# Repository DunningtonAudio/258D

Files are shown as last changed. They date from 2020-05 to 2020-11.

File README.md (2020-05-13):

# 258D
A dual oscillator project

The 258D Dual Oscillator is designed to replicate the functionality of the Buchla 258C module using modern construction techniques and readily available parts. Like Mark Verbos’ 258V and Dustin Stroh’s 258J, the 258D uses the exponential converter and triangle core from the Electronotes VCO option 3, designed by Bernie Hutchins, with output waveshaping derived from Don Buchla’s original 258 Design.

Additionally, the 258D includes:

* A stable voltage reference to isolate the frequency controls from fluctuations and noise on the power supply rails.
* High frequency compensation for improved tracking.
* A scaled V/O CV input in place of the original scaling potentiometer.
* The option to select either saw or square waveshapes for each oscillator by setting a jumper on the rear of the module.
* A buffered copy of the triangle core replacing the rightmost output of each oscillator.
 
There are several build options to adjust the function of the module to a particular users requirements.

The repository contains:

* KiCad project files
* Schematic and build/calibration notes as PDF files
* Bill of Materials in ODS format
* Interactive webpage for matching BOM items to PCB locations

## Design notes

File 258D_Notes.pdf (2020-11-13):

258D Dual Oscillator

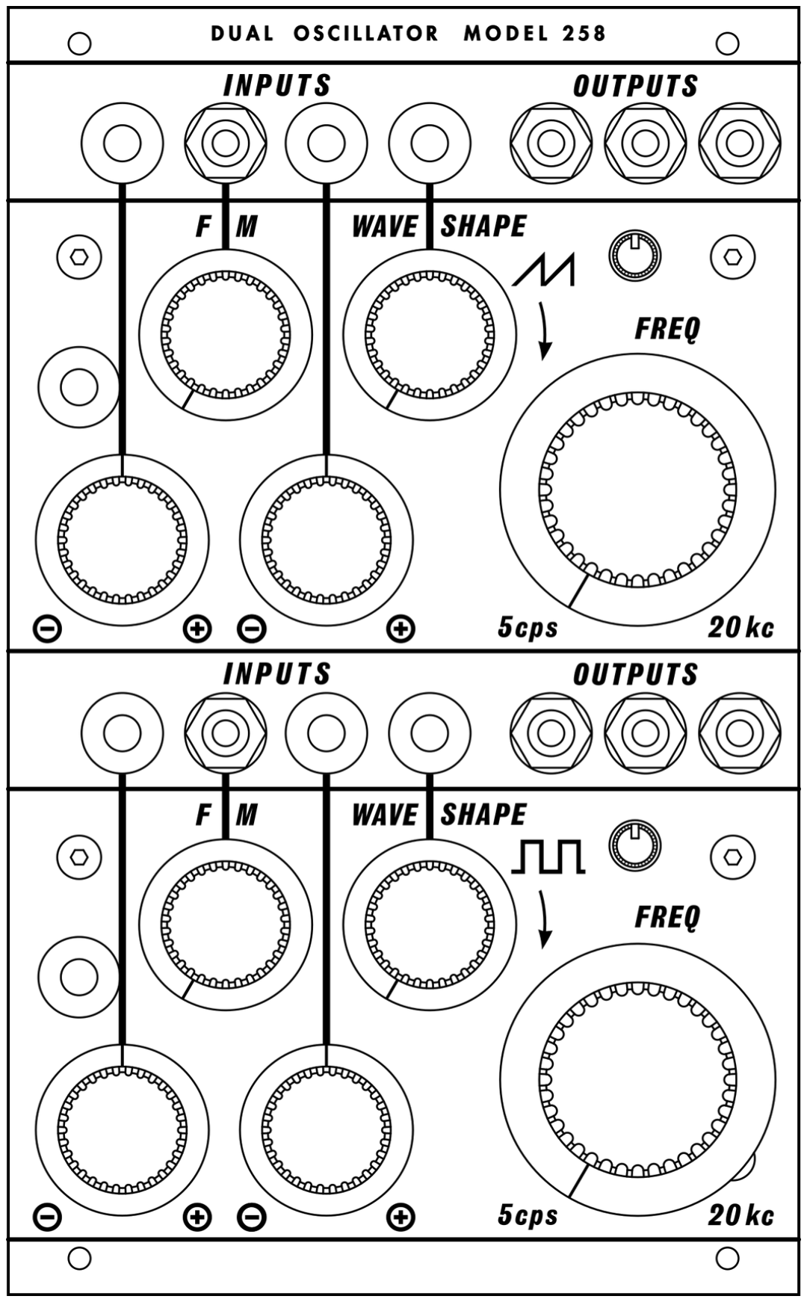
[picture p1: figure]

The 258D Dual Oscillator is designed to replicate the functionality of the Buchla 258C module using modern construction techniques and readily available parts. Like Mark Verbos’ 258V and Dustin Stroh’s 258J, the 258D uses the exponential converter and triangle core from the Electronotes VCO option 3, designed by Bernie Hutchins, with output waveshaping derived from Don Buchla’s original 258 Design.

Additionally, the 258D includes:

- A stable voltage reference to isolate the frequency controls from fluctuations and noise on the power supply rails
- High frequency compensation for improved tracking
- A scaled V/O CV input in place of the original scaling potentiometer
- The option to select either saw or square waveshapes for each oscillator by setting a jumper on the rear of the module
- A buffered copy of the triangle core replacing the rightmost output of each oscillator

Build Notes:

** The 258D is designed to be suitable for hand assembly, but it is not recommended as a “learn surface mount” starting point. You should at a minimum have a temperature controlled soldering iron with a reasonably fine point and good quality solder 0.5mm diameter or finer. Some form of magnification may be beneficial for placing/inspecting the SOT-363 packages. **

Note that Q105/205 should have their VGS(off) selected between 0.8V and 1.2V for best sine shape (ideal value is 1.13V), you should buy more than you need for the best chance of success.

It is recommended that the circuit board is populated in the following order:

- SOT-363 packages (note polarity – these are not symmetrical!)
- SOT-23 packages
- SOIC packages
- 0805 passives (Use the minimum temperature/time possible when soldering film capacitors C101/201)
- Trimmer potentiometers
- Electrolytic capacitors
- Through hole pin headers
- Power wiring harness

Connectors should have their wire links attached and be mounted to the front panel, along with standoffs. Front panel potentiometers can then be loosely fitted into the PCB and the panel and PCB brought together before gently tightening the potentiometer fixing nuts and soldering the potentiometers and connector to PCB wires into place.

Modifications:

There are a number of changes that can be made to alter the behaviour of the module to suit the needs of the end user:

- Resistors R103/203 set the range of the coarse frequency pot. A value of 150k matches the response approximately to the front panel scale of 5Hz to 20kHz. A value of 180k reduces the range to around 5Hz to 12kHz which improves the ease of tuning if using the oscillators for pitched material. Higher frequencies are still available using external CV.
- Resistors R105/205 set the range of the V/O scaling. A value of 120k gives good adjustment for 1.2 V/O scaling. For 1 V/O scaling, reduce the value, or for 2 V/O scaling increase it.
- The waveshapes available from each oscillator can be selected between sine/saw and sine/square by changing the location of a jumper on the rear of the PCB. After changing this setting, SHAPE ZERO should be recalibrated.

Calibration procedure:

Equipment required:
- Power supply delivering +/- 15V, current limit at 50mA
- Oscilloscope
- DC Voltage source capable of 0-10V to 1mV accuracy
- Frequency counter and/or tuner

The following steps should be repeated for each oscillator:

1. Fit shape select jumpers for desired shape on both oscillators.
2. Set front panel controls as follows:
- VR103/104/203/24 CV inputs 1 & 2 – Centre
- VR105/205 FM input – Fully CCW
- VR106/206 Wave Shape – Fully CCW
- VR101/201 Coarse Frequency – Fully CCW
- VR102/202 Fine tune - Centre
3. Set trimpots as follows (direction as viewed from the rear of the module):
- TR103/203 V/O SCALE – Centre
- TR102/202 HF COMP – Fully CW
- TR105/205 SHAPE ZERO – Fully CW
- TR101/201 FREQ OFFSET – Centre
- TR104/204 SINE SHAPE – Centre
4. Apply power to the module and check for approx 35mA draw on each rail.
5. Connect the rightmost output of the oscillator to the oscilloscope and check for approx 4.5V pk-pk triangle wave. Repeat for leftmost output and check for approx 4.5V pk-pk sine wave.
6. Adjust coarse frequency control for approx. 1kHz output. Adjust SINE SHAPE trimpot for best sine shape. If a good sinewave cannot be obtained when the trimpot is fully CCW, decrease the value of R142/R242.
7. Adjust SHAPE ZERO trimpot CCW until a small spike becomes visible at the low peak of the sinewave output, then back off slightly. The front panel Wave Shape control should now give a good range of control from sine to saw/square. Reset the front panel control fully CCW. Check for roughly equivalent response when applying 10V from the DC voltage source to the wave shape CV input.
8. Connect the leftmost output of the oscillator to the frequency counter/tuner. Set the DC voltage source to 0V and connect its output to the scaled (grey) CV input of the oscillator. Using the front panel coarse/fine frequency controls, set the oscillator frequency to 16.35Hz/C0. Set the output of the DC voltage source to 6.0V and check the output frequency – if it is higher than 523.25Hz/C5, adjust the V/O SCALE trimpot slightly CCW, or slightly CW if the output is lower (reverse the direction if a 3314J single turn pot is used). Reset the DC voltage source to 0V, set the oscillator output to 16.35Hz/C0 using the front panel controls and repeat the above until the oscillator outputs exactly 16.35Hz/C0 with 0V applied and exactly 523.25Hz/C5 with 6.0V applied.
9. Set the DC voltage source to 7.2V and check the frequency of the output. If it is lower than 1.0465kHz/C6, adjust the HF COMP trimpot slightly CCW. Repeat step 8 and 9 until the best average response between the two is found. It is likely that C6 will be slightly sharp when the rest of the range is well tuned.
10. Set the DC voltage source to 0V. Set the front panel fine tune control to centre and the coarse frequency control fully CW and measure the frequency of the output. Adjust the FREQ OFFSET trimpot for approx 20kHz.

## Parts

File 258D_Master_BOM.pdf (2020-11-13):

258D_Master

Reference | Quantity | Value | Footprint | Manufacturer | MPN | Supplier | Order Code | Description | Notes
PCB Mount
C103 C203 | 2 | 100p | C0805 | Yageo | CC0805JRNPO9BN101 | Mouser | 603-CC0805JRNPO9BN101 | C0G, 50V, 5%
C104 C105 C204 C205 | 4 | 220p | C0805 | Yageo | CC0805JRNPO9BN221 | Mouser | 603-CC0805JRNPO9BN221 | C0G, 50V, 5%
C101 C201 | 2 | 2n2 | C0805 | Panasonic | ECH-U1C222GX5 | Mouser | 667-ECH-U1C222GX5 | PPS, 16V, 2%
C1-C4, C106-C113, C206-C213 | 20 | 100n | C0805 | Yageo | CC0805KRX7R9BB104 | Mouser | 603-CC0805KRX7R9BB104 | X7R,50V, 10%
C102 C114 C115 C202 C214 C215 | 6 | 22u | CE5x5.8 | Panasonic | EEE-FK1V220AR | Mouser | 667-EEE-FK1V220AR | 35V, 20%, 105deg
D101 D102 D201 D202 | 4 | BAW56 | SOT-23-3 | On Semiconductor | BAW56LT1G | Mouser | 863-BAW56LT1G | Common anode dual diode
L1 L2 L101 L102 L201 L202 | 6 | 10u | L0805 | Taiyo Yuden | LBC2012T100K | Mouser | 963-LBC2012T100K | 1.2R, 200mA, 10%
Q101 Q201 | 2 | DMMT3906W | SOT-363 | Diodes Inc | DMMT3906W-7-F | Mouser | 621-DMMT3906W-F | Dual matched PNP | Note polarity – these are not symmetrical!
Q102 Q202 | 2 | DMMT3904W | SOT-363 | Diodes Inc | DMMT3904W-7-F | Mouser | 621-DMMT3904W-F | Dual matched NPN | Note polarity – these are not symmetrical!
Q103 Q203 | 2 | MMBT3906 | SOT-23-3 | On Semiconductor | MMBT3906LT1G | Mouser | 863-MMBT3906LT1G | PNP
Q104 Q204 | 2 | MMBF5485 | SOT-23-3 | On Semiconductor | MMBF5485 | Mouser | 512-MMBF5485 | N-Channel JFET
Q105 Q205 | 2 | MMBFJ201 | SOT-23-3 | On Semiconductor | MMBFJ201 | Mouser | 512-MMBFJ201 | N-Channel JFET | Select for VGS(off) = 0.7V – 1.2V; ideal value is 1.13V
R117 R217 | 2 | 390R | R0805 | Yageo | RC0805FR-07390RL | Mouser | 603-RC0805FR-07390RL | 150V, 125mW, 1%, 100PPM
R146 R246 | 2 | 470R | R0805 | Yageo | RC0805FR-07470RL | Mouser | 603-RC0805FR-07470RL | 150V, 125mW, 1%, 100PPM
R140 R141 R148 R151 R152 R240 R241 R248 R251 R252 | 10 | 680R | R0805 | Yageo | RC0805FR-07680RL | Mouser | 603-RC0805FR-07680RL | 150V, 125mW, 1%, 100PPM
R114 R145 R214 R245 | 4 | 1k8 | R0805 | Yageo | RC0805FR-071K8L | Mouser | 603-RC0805FR-071K8L | 150V, 125mW, 1%, 100PPM
R116 R216 | 2 | 2k | R0805 | TE Connectivity | LT732K0JTG | Small Bear | 2530 | PTC 5% | Alt. Farnell p/n 1174317
R147 R247 | 2 | 2k2 | R0805 | Yageo | RC0805FR-072K2L | Mouser | 603-RC0805FR-072K2L | 150V, 125mW, 1%, 100PPM
R133 R233 | 2 | 2k49 | R0805 | Yageo | RC0805FR-072K49L | Mouser | 603-RC0805FR-072K49L | 150V, 125mW, 1%, 100PPM
R124 R149 R224 R249 | 4 | 3k3 | R0805 | Yageo | RC0805FR-073K3L | Mouser | 603-RC0805FR-073K3L | 150V, 125mW, 1%, 100PPM
R119 R219 | 2 | 4k99 | R0805 | Yageo | RC0805FR-074K99L | Mouser | 603-RC0805FR-074K99L | 150V, 125mW, 1%, 100PPM
R129 R142 R143 R229 R242 R243 | 6 | 6k8 | R0805 | Yageo | RC0805FR-076K8L | Mouser | 603-RC0805FR-076K8L | 150V, 125mW, 1%, 100PPM
R150 R250 | 2 | 9k1 | R0805 | Yageo | RC0805FR-079K1L | Mouser | 603-RC0805FR-079K1L | 150V, 125mW, 1%, 100PPM
| 10 | 10k | R0805 | Yageo | RC0805FR-0710KL | Mouser | 603-RC0805FR-0710KL | 150V, 125mW, 1%, 100PPM
R121 R125 R130 R221 R225 R230 | 6 | 15k | R0805 | Yageo | RC0805FR-0715KL | Mouser | 603-RC0805FR-0715KL | 150V, 125mW, 1%, 100PPM
R118 R144 R218 R244 | 4 | 33k | R0805 | Yageo | RC0805FR-0733KL | Mouser | 603-RC0805FR-0733KL | 150V, 125mW, 1%, 100PPM
R120 R126 R220 R226 | 4 | 68k | R0805 | Yageo | RC0805FR-0768KL | Mouser | 603-RC0805FR-0768KL | 150V, 125mW, 1%, 100PPM
R107 R111 R113 R207 R211 R213 | 6 | 100k | R0805 | Yageo | RC0805FR-07100KL | Mouser | 603-RC0805FR-07100KL | 150V, 125mW, 1%, 100PPM
R105 R205 | 2 | 120k | R0805 | Yageo | RC0805FR-07120KL | Mouser | 603-RC0805FR-07120KL | 150V, 125mW, 1%, 100PPM | SOT for correct V/O scaling
R103 R123 R128 R203 R223 R228 | 6 | 150k | R0805 | Yageo | RC0805FR-07150KL | Mouser | 603-RC0805FR-07150KL | 150V, 125mW, 1%, 100PPM
R101 R102 R201 R202 | 4 | 180k | R0805 | Yageo | RC0805FR-07180KL | Mouser | 603-RC0805FR-07180KL | 150V, 125mW, 1%, 100PPM
R134 R137 R138 R139 R234 R237 R238 R239 | 8 | 330k | R0805 | Yageo | RC0805FR-07330KL | Mouser | 603-RC0805FR-07330KL | 150V, 125mW, 1%, 100PPM
R112 R132 R212 R232 | 4 | 390k | R0805 | Yageo | RC0805FR-07390KL | Mouser | 603-RC0805FR-07390KL | 150V, 125mW, 1%, 100PPM
R135 R235 | 2 | 430k | R0805 | Yageo | RC0805FR-07430KL | Mouser | 603-RC0805FR-07430KL | 150V, 125mW, 1%, 100PPM
R127 R227 | 2 | 680k | R0805 | Yageo | RC0805FR-07680KL | Mouser | 603-RC0805FR-07680KL | 150V, 125mW, 1%, 100PPM
R131 R136 R231 R236 | 4 | 820k | R0805 | Yageo | RC0805FR-07820KL | Mouser | 603-RC0805FR-07820KL | 150V, 125mW, 1%, 100PPM
R108 R110 R208 R210 | 4 | 1M5 | R0805 | Yageo | RC0805FR-071M5L | Mouser | 603-RC0805FR-071M5L | 150V, 125mW, 1%, 100PPM
R104 R204 | 2 | 2M7 | R0805 | Yageo | RC0805FR-072M7L | Mouser | 603-RC0805FR-072M7L | 150V, 125mW, 1%, 100PPM
TR103 TR203 | 2 | 100R | 3314J | Bourns | 3224W-1-101E | Mouser | 652-3224W-1-101E | 500V,250mW, 20%, 100PPM
TR104 TR204 | 2 | 20k | 3314J | Bourns | 3314J-1-203E | Mouser | 652-3314J-1-203E | 500V,250mW, 20%, 100PPM
TR101 TR102 TR201 TR202 | 4 | 100k | 3314J | Bourns | 3314J-1-104E | Mouser | 652-3314J-1-104E | 500V,250mW, 20%, 100PPM
TR105 TR205 | 2 | 1M | 3314J | Bourns | 3314J-1-105E | Mouser | 652-3314J-1-105E | 500V,250mW, 20%, 100PPM
U1 | 1 | ADR01 | SOIC08 | Analog Devices | ADR01ARZ | Mouser | 584-ADR01ARZ | 10V reference, 0.1%, 3PPM
U101 U201 | 2 | TL074 | SOIC14 | Texas Instruments | TL074IDR | Mouser | 595-TL074IDR | Quad operational amplifier, JFET input
U102 U202 | 2 | LM13700 | SOIC16 | Texas Instruments | LM13700MX/NOPB | Mouser | 926-LM13700MX/NOPB | Dual transconductance amplifier
U103 U203 | 2 | TL072 | SOIC08 | Texas Instruments | TL072IDR | Mouser | 595-TL072IDR | Dual operational amplifier, JFET input
U2 U104 U204 | 3 | TL071 | SOIC08 | Texas Instruments | TL071IDR | Mouser | 595-TL071IDR | Operational amplifier, JFET input
VR102 VR202 | 2 | 100k Lin | RD901F-40-00D | Song Huei | R0904N-B100K-L-25KQ | Small Bear | 1012A4-B100K | 9mm RA PCB mount potentiometer
VR101 VR103 VR104 VR106 VR201 VR203 VR204 VR206 | 8 | 100k Lin | RV16AF-41-(L)R1-XXX | Alpha | RV16AF-41-15R1-104B | Small Bear | 1011 B100K | 16mm RA PCB mount potentiometer | Snap off locating lug
VR105 VR205 | 2 | 100k Log | RV16AF-41-(L)R1-XXX | Alpha | RV16AF-41-15R1-104A | Small Bear | 1011 A100K | 16mm RA PCB mount potentiometer | Snap off locating lug
| 10 | | | Alpha | M7x0.75 | Small Bear | 1018 | Toothed washer for 16mm potentiometer | Fit between potentiometer body and panel
| 10 | | | Alpha | | Small Bear | 1011AM | Dust cover for 16mm potentiometer | Fit on all 16mm potentiometers
J106-J108, J206-J208 | 2 | Shape Sel | | Samtec | TSW-103-07-F-T | Mouser | 200-TSW10307GT | 3R3P header 2.54mm | Alt. Farnell p/n 2050709

R1 R2 R106 R109 R115 R122 R206 R209 R215 R222

258D_Master

Reference | Quantity | Value | Footprint | Manufacturer | MPN | Supplier | Order Code | Description | Notes
Panel Mount
J101 J102 J105 J201 J202 J205 | 6 | CV inputs | Johnson | 108-0903-001 | Mouser | 530-108-0903-1 | Black banana jack
J103 J203 | 2 | V/O input | Johnson | 108-0913-001 | Mouser | 530-108-0913-1 | Grey banana jack
J104 J109 J110 J111 J204 J209 J210 J211 | 8 | Audio IO | Switchcraft | 41 | Mouser | 502-41 | Tinijax
24awg wire black 25mm length | 14 | | Alpha Wire | 892419 BK005 | Mouser | 602-892419-100-02 | Wiring to CV inputs + audio shields | Strip 4mm each end. Order code is for 30.5m reel.
24awg wire grey 25mm length | 2 | | Alpha Wire | 892419 SL005 | Mouser | 602-892419-100-09 | Wiring to V/O inputs | Strip 4mm each end. Order code is for 30.5m reel.
24awg wire white 25mm length | 8 | | Alpha Wire | 892419 WH005 | Mouser | 602-892419-100-01 | Wiring to Audio IO | Strip 4mm each end. Order code is for 30.5m reel.
Hardware & Misc
PCB | 1 | | Dunnington Audio | | thebeast.co.uk | http://thebeast.co.uk/?product=Printed circuit board
Front panel | 1 | | The Beast | | thebeast.co.uk | http://thebeast.co.uk/?product | Front panel | If using alternate panels, drill out the scale trim pot holes to 8.5mm
M3x14mm F-F Standoff | 5 | | Harwin | R30-1001402 | Mouser | 855-R30-1001402
M3x6mm Pozi CSK | 5 | | RS Pro | | RS | 528-946 | | Panel to standoff fixing
M3x6mm Pozi Pan SEMS | 5 | | RS Pro | | RS | 279-149 | | PCB to standoff fixing
M3 Toothed Washer | 5 | | RS Pro | | RS | 526-574 | | Fit between standoffs and panel
Small Knob | 8 | | Davies Molding | 1610AA | Mouser | 5164-1610AA | | Fit on VR103-VR106 & VR203-VR206
Large knob | 2 | | Davies Molding | 1600BM | Mouser | 5164-1600BM | | Fit on VR101 & VR201
J1 | 1 | Power | EDAC | 306-010-500-102 | Mouser | 587-306-50-010 | 10P edge connector, 3.96mm
| 1 | | EDAC | 338-240-328 | Mouser | 587-338-240-328 | Polarizing key | Fit in position 7 of power EDAC
20awg wire black 350mm length | 1 | Q | Alpha Wire | 892019 BK005 | Mouser | 602-892019-100-02 | | EDAC position 1. Order code is for 30.5m reel.
20awg wire white 350mm length | 1 | -15V | Alpha Wire | 892019 WH005 | Mouser | 602-892019-100-01 | | EDAC position 2. Order code is for 30.5m reel.
20awg wire red 350mm length | 1 | +15V | Alpha Wire | 892019 RD005 | Mouser | 602-892019-100-03 | | EDAC position 3. Order code is for 30.5m reel.
Expandable Sleeving 3mm 300mm | 1 | | Alpha Wire | GRP1301/8 BK007 | Mouser | 602-130018-50BK | | Fit over power cabling
Heatshrink 6.35mm 40mm length | 2 | | Alpha Wire | FIT221V1/4 BK103 | Mouser | 602-221V014-4 | | Fit at each end of expandable sleeving
Heatshrink 3.18mm 12mm length | 3 | | Alpha Wire | FIT221V1/8 BK103 | Mouser | 602-221V018-4 | | Fit over terminated EDAC contacts
Cable ties | 2 | | Panduit | PLT.7M-M | Mouser | 644-PLT.7M-M | | Secure power cabling to PCB and EDAC
Shunt, 3 position | 2 | | Samtec | MNT-103-BK-G | Mouser | 200-MNT103BKG | | Alt. Farnell p/n 2779698 – Fit on Shape Sel headers for desired operation
Thermally conductive epoxy | 1 | | MG Chemicals | 8329TFF-25ML | Mouser | 590-8329TFF-25ML | | Optionally apply over Q101/R116 and Q201/R216

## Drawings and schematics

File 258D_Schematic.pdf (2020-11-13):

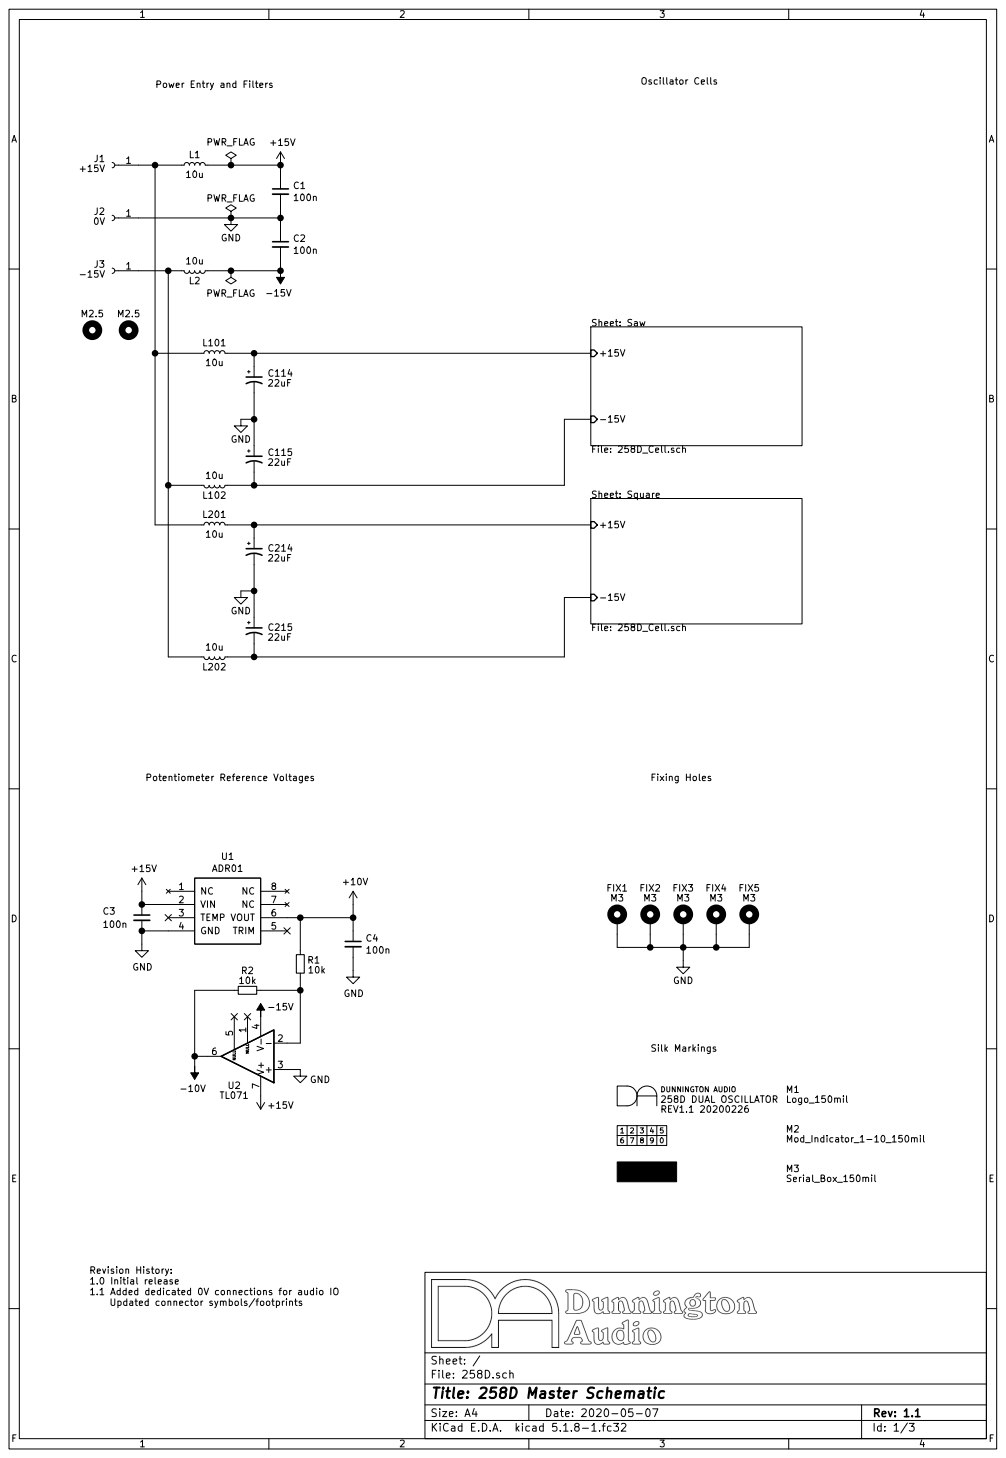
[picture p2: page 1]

Power Entry and Filters

Sheet: Square File: 258D_Cell.sch +15V

Revision History: 1.0 Initial release

1.1 Added dedicated 0V connections for audio IO
Updated connector symbols/footprints

File: 258D.sch Sheet: /
Id: 1/3 Title: 258D Master Schematic

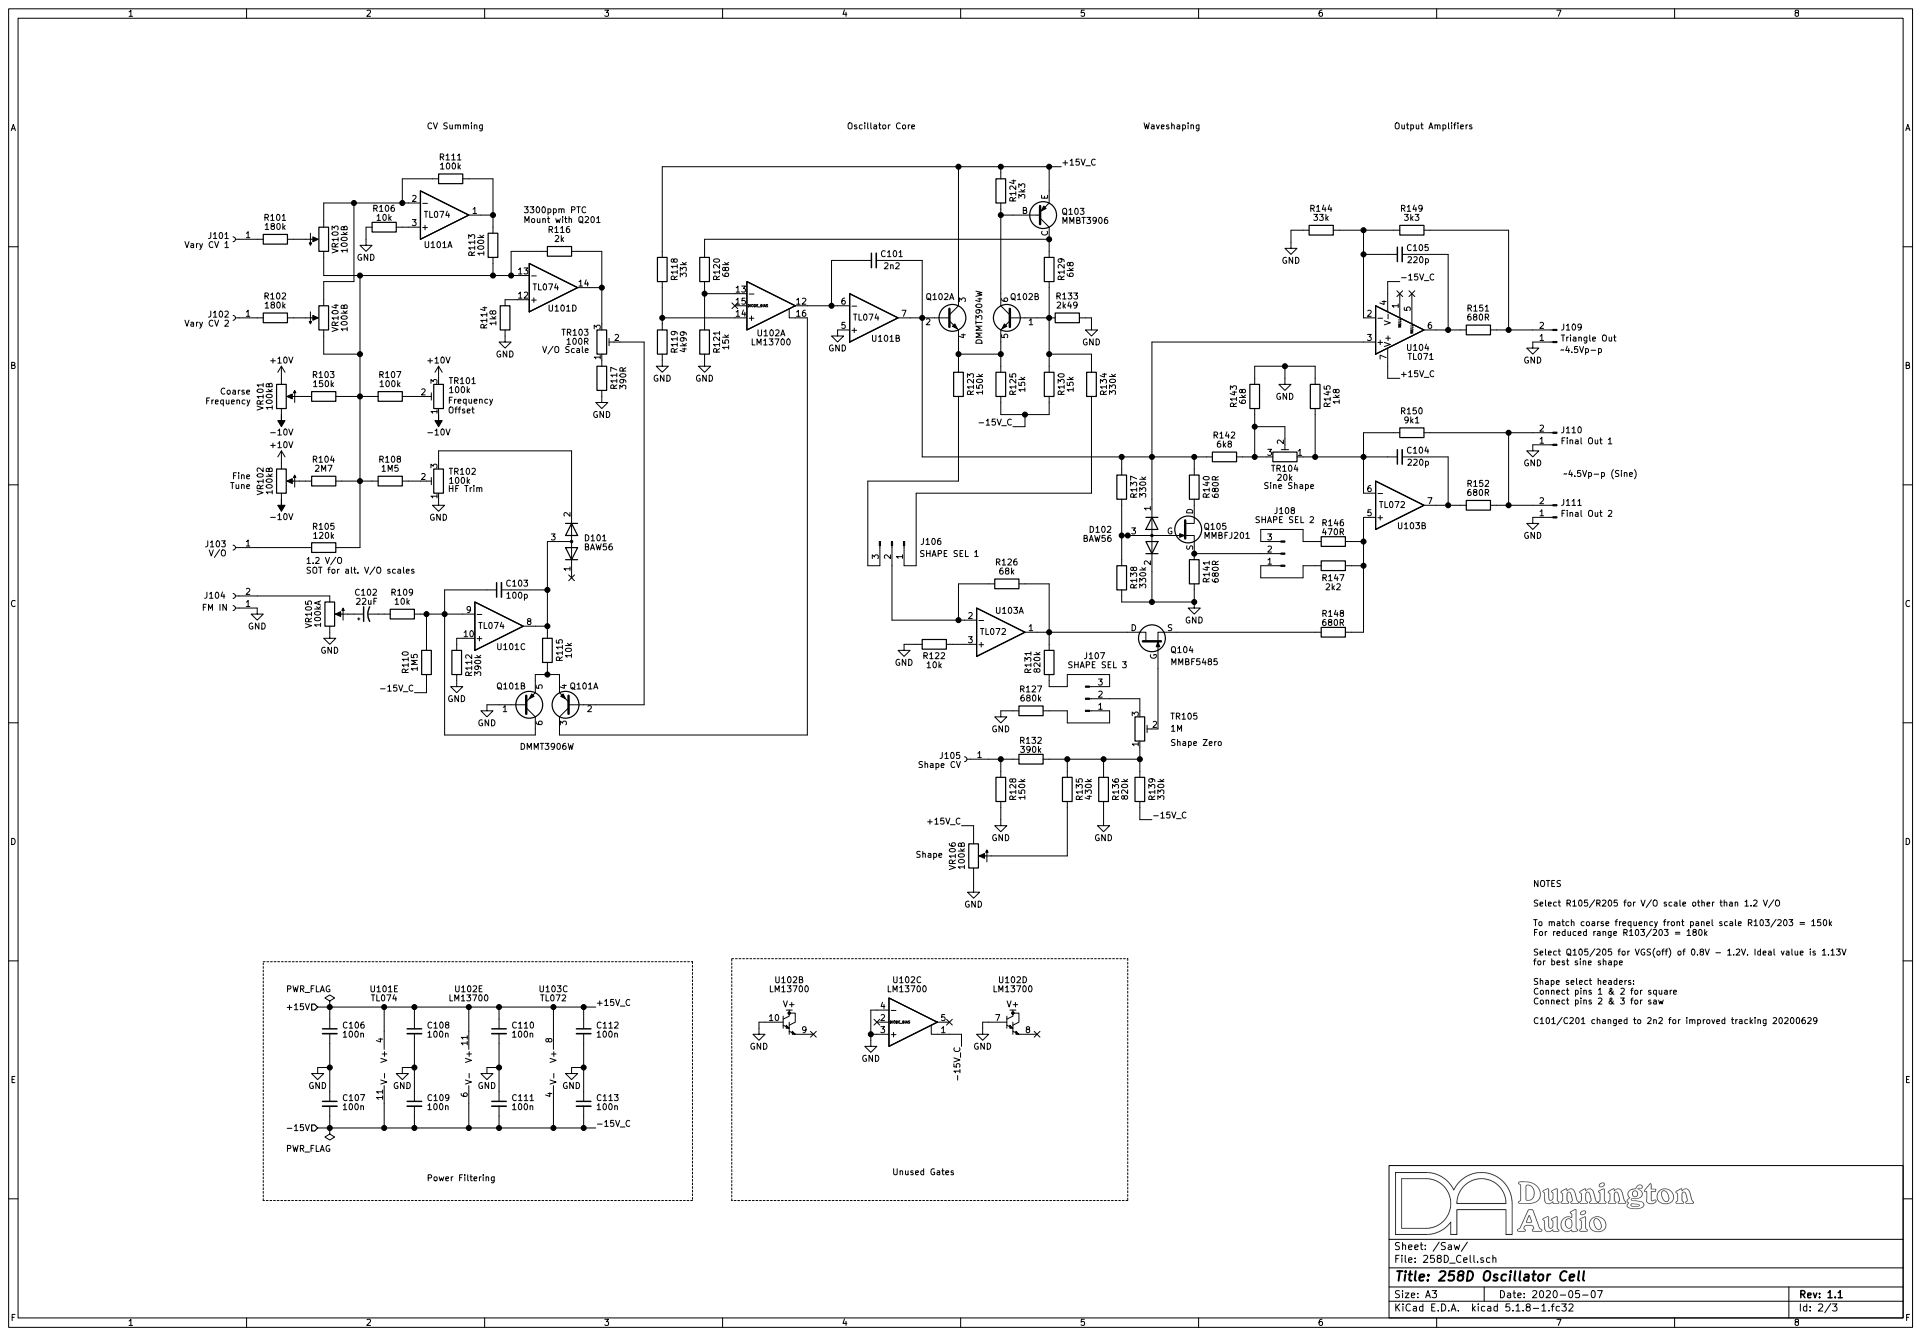
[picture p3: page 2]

SOT for alt. V/O scales

Select R105/R205 for V/O scale other than 1.2 V/O

To match coarse frequency front panel scale R103/203 = 150k
For reduced range R103/203 = 180k

Select Q105/205 for VGS(off) of 0.8V - 1.2V. Ideal value is 1.13V
for best sine shape

Shape select headers:
Connect pins 1 & 2 for square
Connect pins 2 & 3 for saw

C101/C201 changed to 2n2 for improved tracking 20200629

File: 258D_Cell.sch Sheet: /Saw/
Id: 2/3 Title: 258D Oscillator Cell

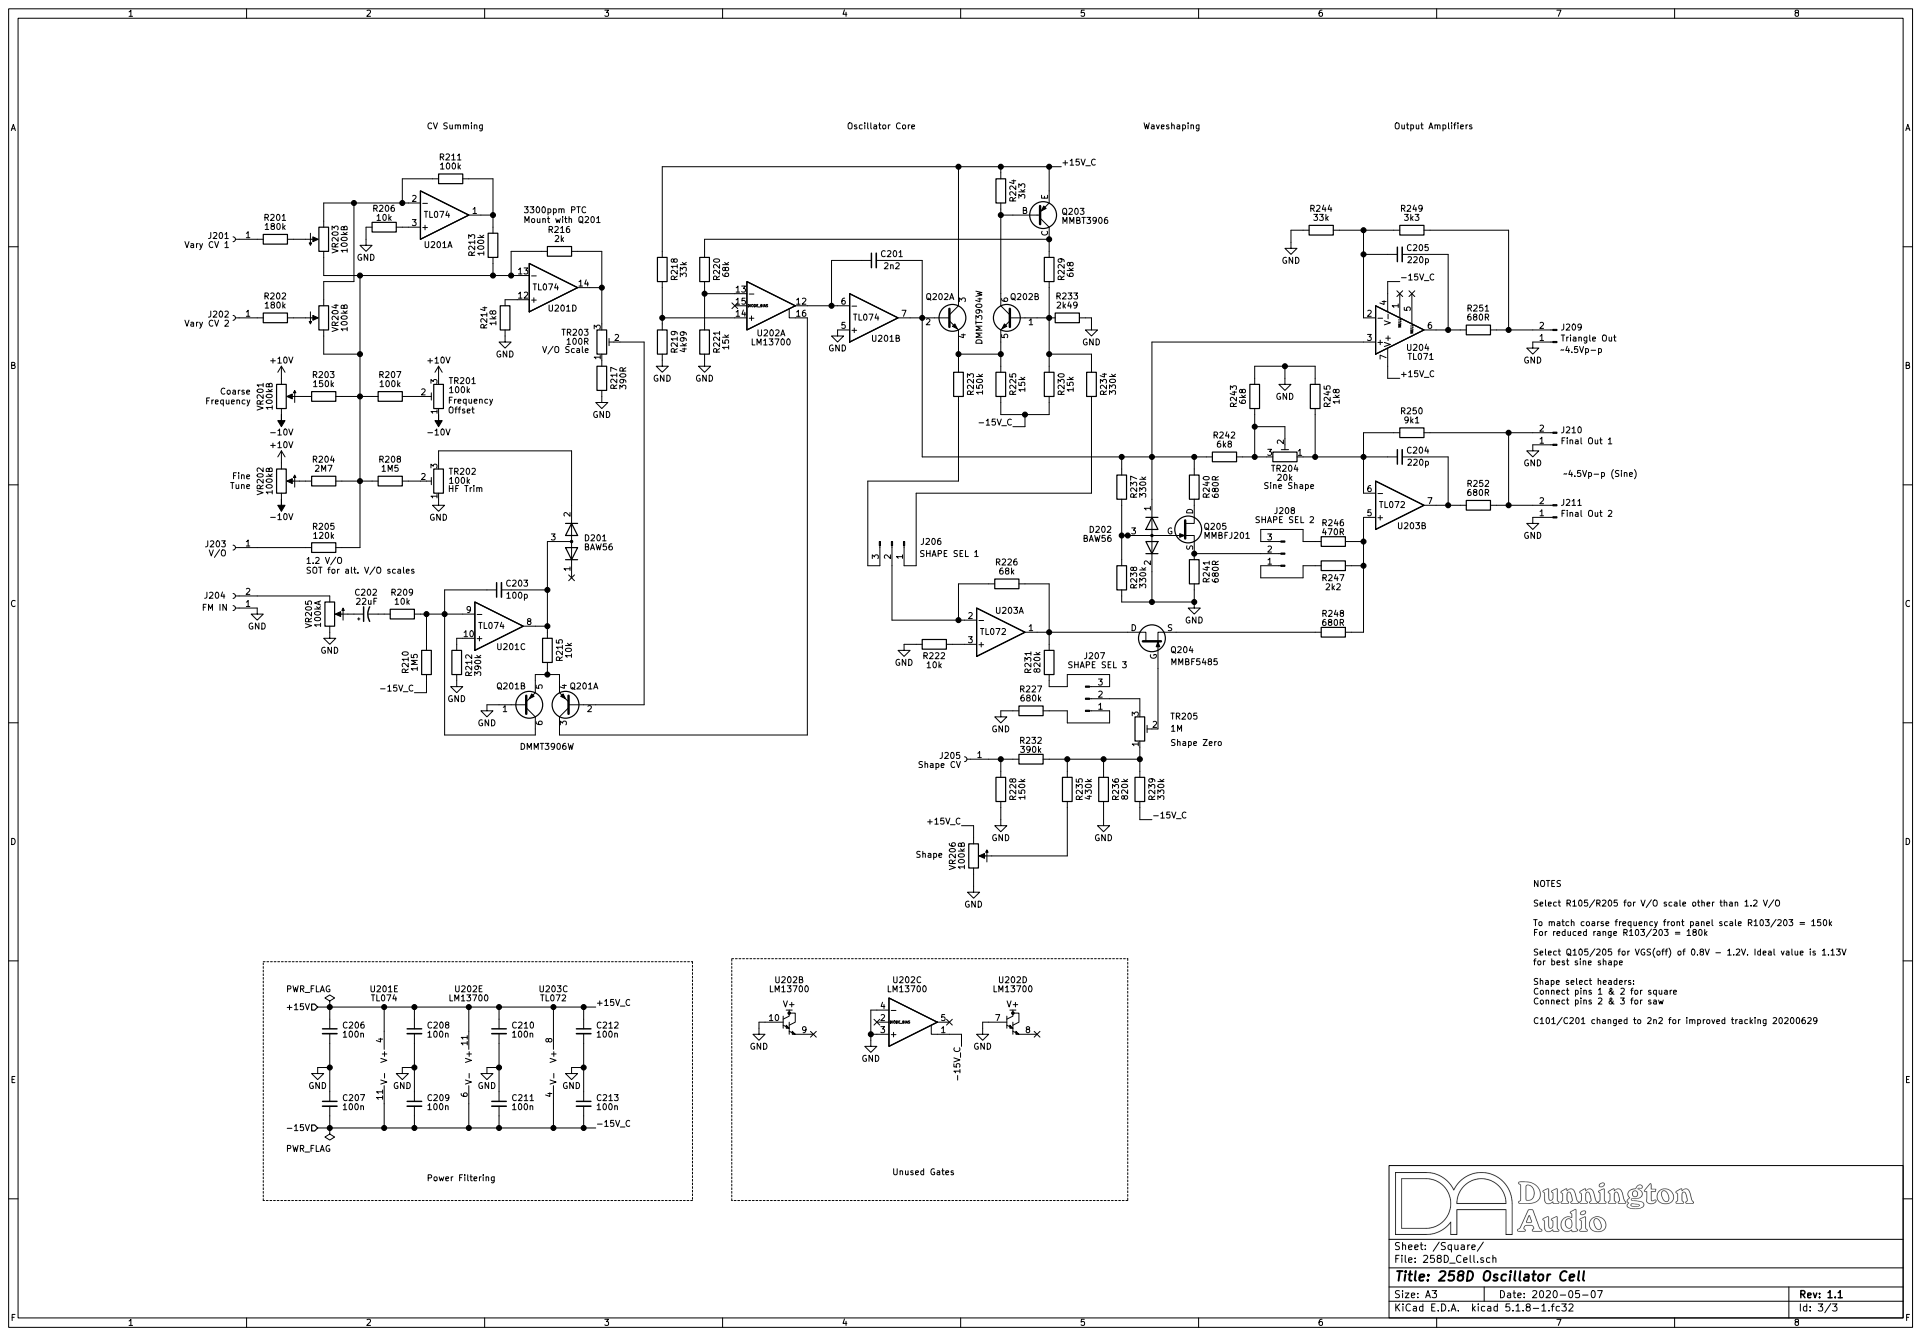
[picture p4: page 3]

SOT for alt. V/O scales

Select R105/R205 for V/O scale other than 1.2 V/O

To match coarse frequency front panel scale R103/203 = 150k
For reduced range R103/203 = 180k

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

Shape select headers:
Connect pins 1 & 2 for square
Connect pins 2 & 3 for saw

C101/C201 changed to 2n2 for improved tracking 20200629

Sheet: /Square/
File: 258D_Cell.sch
Id: 3/3 Title: 258D Oscillator Cell

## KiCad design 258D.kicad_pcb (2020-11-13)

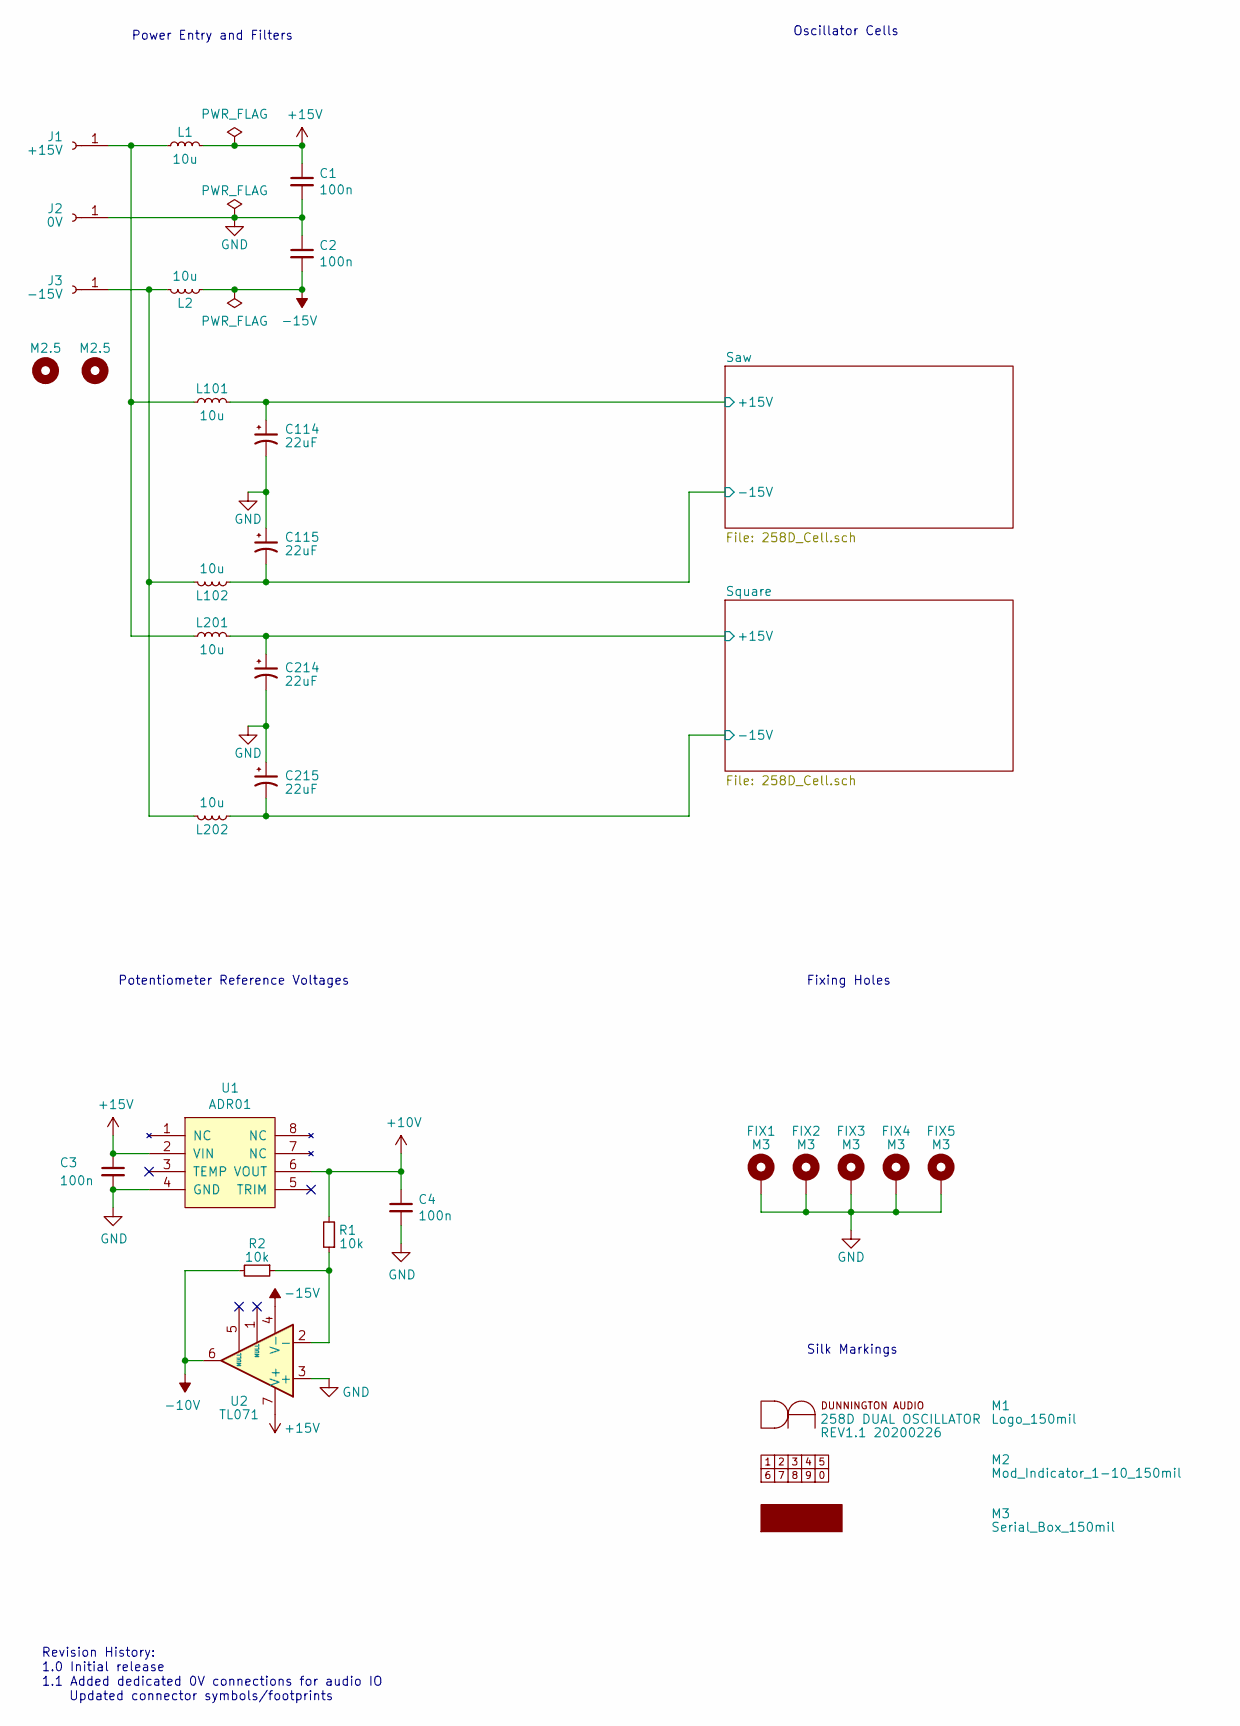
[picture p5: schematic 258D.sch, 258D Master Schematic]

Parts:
C1, C2, C3, C4: 100n; C_0805_2012Metric
C114, C115, C214, C215: 22uF; CP_Elec_5x5.8
FIX1, FIX2, FIX3, FIX4, FIX5: M3; MountingHole_3.2mm_M3_Pad_Via
J1: +15V; SolderWirePad_single_1-2mmDrill
J2: 0V; SolderWirePad_single_1-2mmDrill
J3: -15V; SolderWirePad_single_1-2mmDrill
L1, L2, L101, L102, L201, L202: 10u; L_0805_2012Metric; MPN LBC2012T100K
M1: Logo_150mil
M2: Mod_Indicator_1-10_150mil
M3: Serial_Box_150mil
MK101, MK102: M2.5; MountingHole_2.5mm
R1, R2: 10k; R_0805_2012Metric
U1: ADR01; SOIC-8_3.9x4.9mm_P1.27mm
U2: TL071; SOIC-8_3.9x4.9mm_P1.27mm

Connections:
+10V: C4.1, R1.2, U1.6 (VOUT); also elsewhere on the board
+15V: C1.1, C3.1, L1.2, U1.2 (VIN), U2.7 (V+)
-10V: R2.2, U2.6; also elsewhere on the board
-15V: C2.2, L2.2, U2.4 (V-)
/Saw/+15V: C114.1, L101.2; also elsewhere on the board
/Saw/-15V: C115.2, L102.2; also elsewhere on the board
/Square/+15V: C214.1, L201.2; also elsewhere on the board
/Square/-15V: C215.2, L202.2; also elsewhere on the board
GND: C1.2, C2.1, C3.2, C4.2, C114.2, C115.1, C214.2, C215.1, FIX1.1, FIX2.1, FIX3.1, FIX4.1, FIX5.1, J2.1, U1.4 (GND), U2.3 (+); also elsewhere on the board
unnamed: J1.1, L1.1, L101.1, L201.1
unnamed: J3.1, L2.1, L102.1, L202.1
unnamed: R1.1, R2.1, U2.2 (-)

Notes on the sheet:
Oscillator Cells
Fixing Holes
Potentiometer Reference Voltages
Power Entry and Filters
Revision History: 1.0 Initial release 1.1 Added dedicated 0V connections for audio IO Updated connector symbols/footprints
Silk Markings

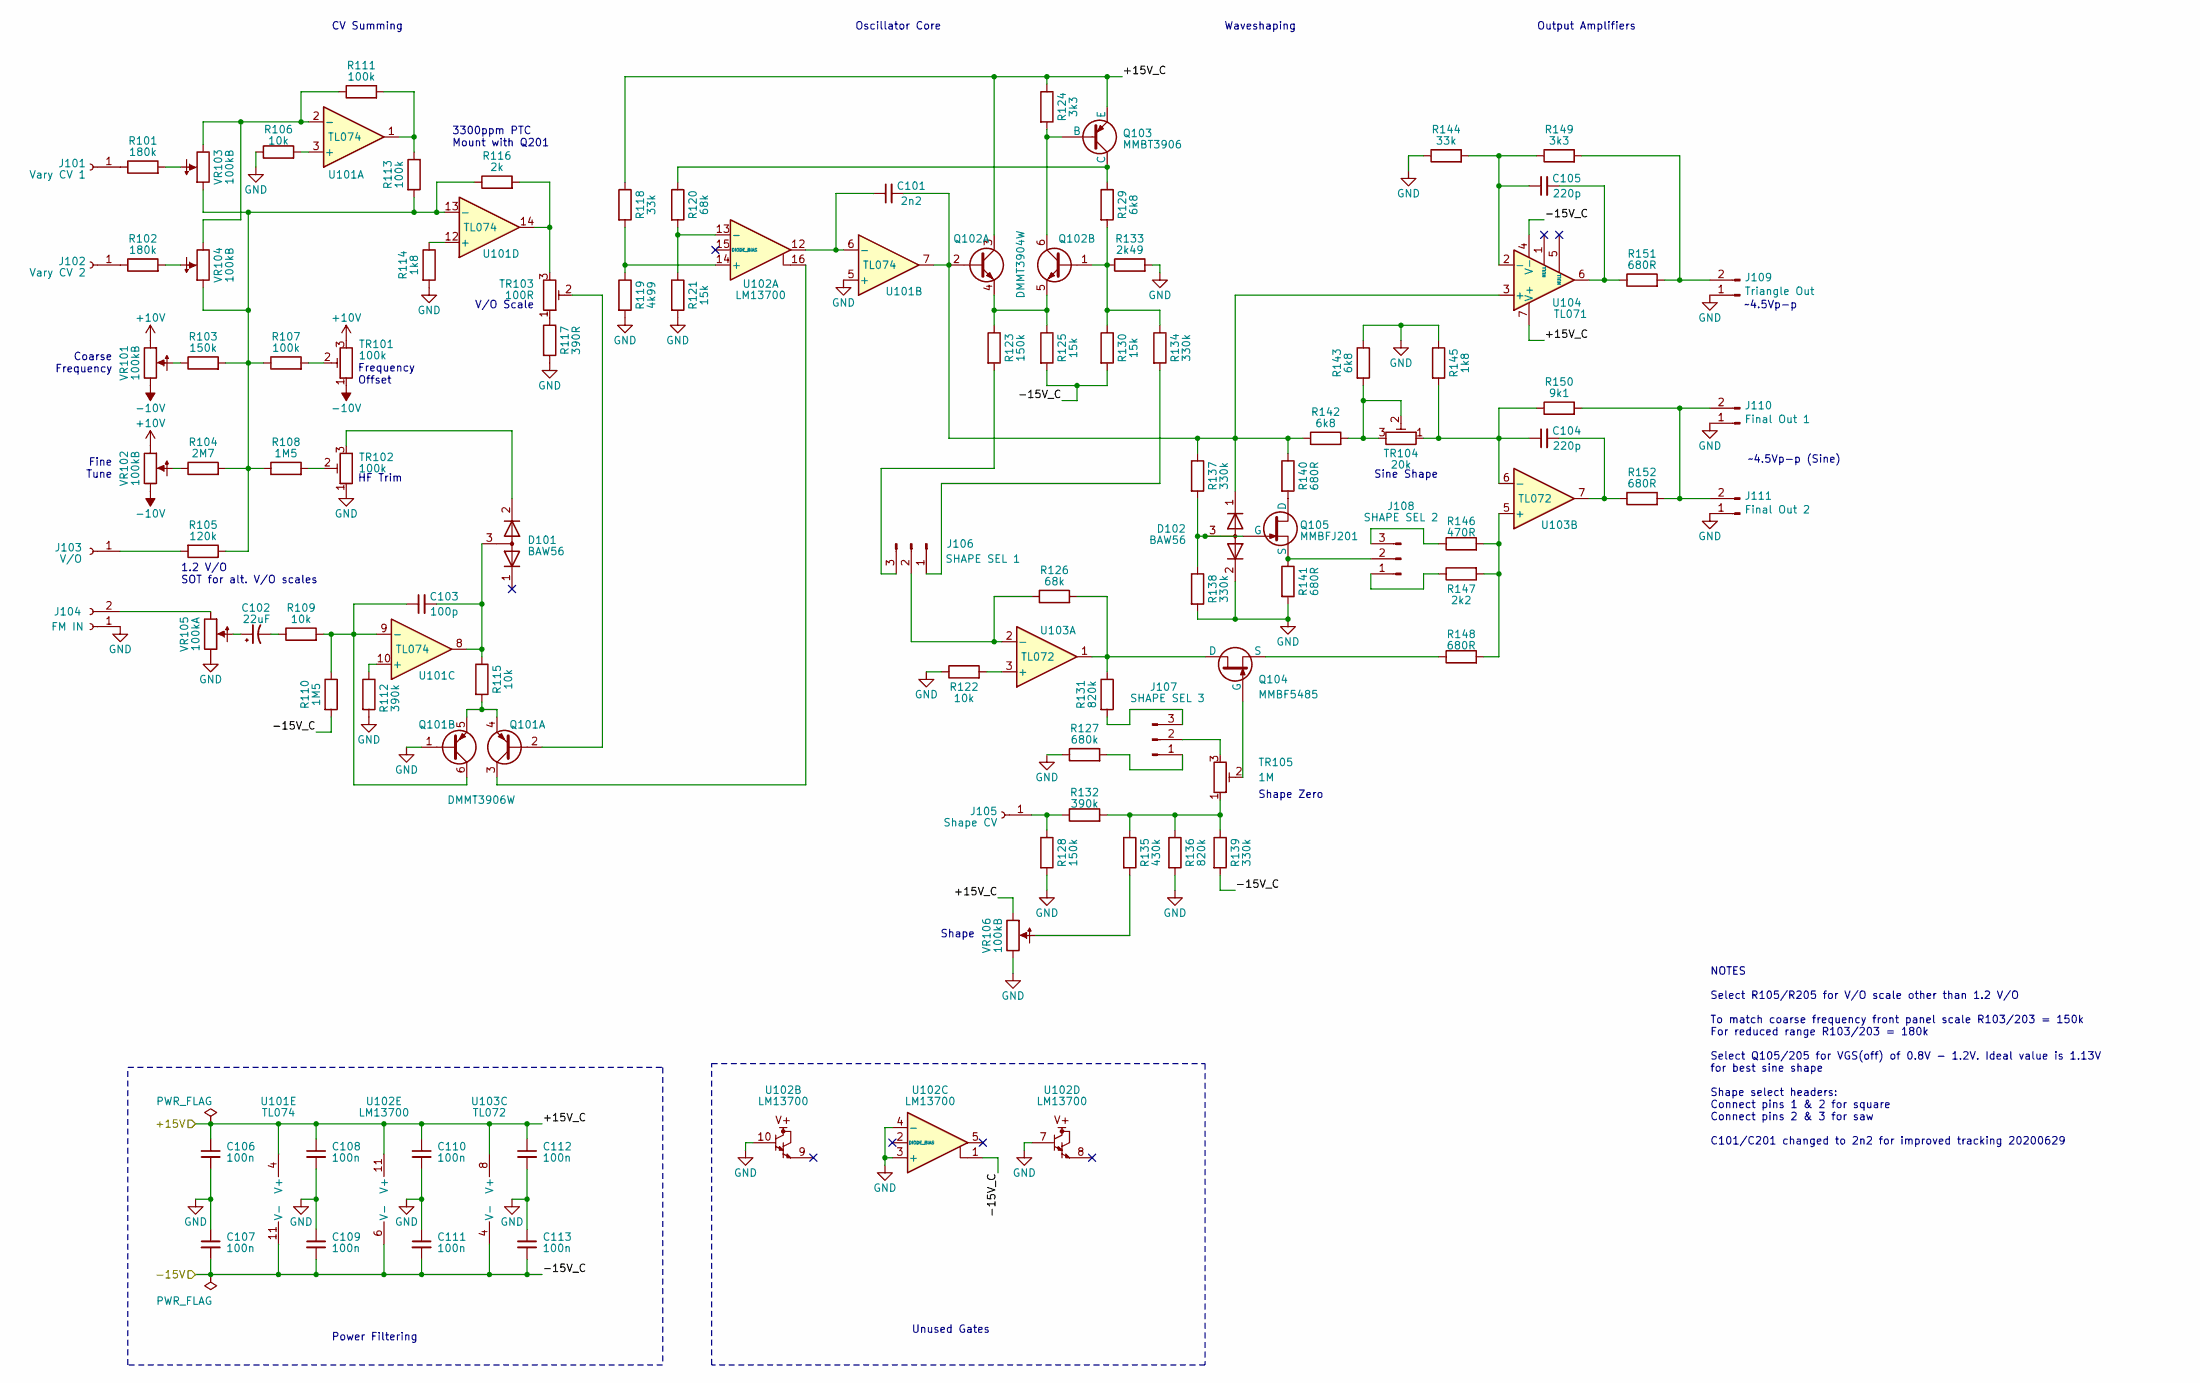
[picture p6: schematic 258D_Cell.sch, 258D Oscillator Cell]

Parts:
C101: 2n2; C_0805_2012Metric
C102: 22uF; CP_Elec_5x5.8
C103: 100p; C_0805_2012Metric
C104, C105: 220p; C_0805_2012Metric
C106, C107, C108, C109, C110, C111, C112, C113: 100n; C_0805_2012Metric
D101, D102: BAW56; SOT-23
J101: Vary CV 1; Johnson_108-09XX-001
J102: Vary CV 2; Johnson_108-09XX-001
J103: V/O; Johnson_108-09XX-001
J104: FM IN; Switchcraft_41
J105: Shape CV; Johnson_108-09XX-001
J106: SHAPE SEL 1; PinHeader_1x03_P2.54mm_Vertical
J107: SHAPE SEL 3; PinHeader_1x03_P2.54mm_Vertical
J108: SHAPE SEL 2; PinHeader_1x03_P2.54mm_Vertical
J109: Triangle Out; Switchcraft_41
J110: Final Out 1; Switchcraft_41
J111: Final Out 2; Switchcraft_41
Q101: DMMT3906W; SOT-363_SC-70-6
Q102: DMMT3904W; SOT-363_SC-70-6
Q103: MMBT3906; SOT-23
Q104: MMBF5485; SOT-23
Q105: MMBFJ201; SOT-23
R101, R102: 180k; R_0805_2012Metric
R103, R123, R128: 150k; R_0805_2012Metric
R104: 2M7; R_0805_2012Metric
R105: 120k; R_0805_2012Metric
R106, R109, R115, R122: 10k; R_0805_2012Metric
R107, R111, R113: 100k; R_0805_2012Metric
R108, R110: 1M5; R_0805_2012Metric
R112, R132: 390k; R_0805_2012Metric
R114, R145: 1k8; R_0805_2012Metric
R116: 2k; R_0805_2012Metric
R117: 390R; R_0805_2012Metric
R118, R144: 33k; R_0805_2012Metric
R119: 4k99; R_0805_2012Metric
R120, R126: 68k; R_0805_2012Metric
R121, R125, R130: 15k; R_0805_2012Metric
R124, R149: 3k3; R_0805_2012Metric
R127: 680k; R_0805_2012Metric
R129, R142, R143: 6k8; R_0805_2012Metric
R131, R136: 820k; R_0805_2012Metric
R133: 2k49; R_0805_2012Metric
R134, R137, R138, R139: 330k; R_0805_2012Metric
R135: 430k; R_0805_2012Metric
R140, R141, R148, R151, R152: 680R; R_0805_2012Metric
R146: 470R; R_0805_2012Metric
R147: 2k2; R_0805_2012Metric
R150: 9k1; R_0805_2012Metric
TR101, TR102: 100k; Potentiometer_Bourns_3314J_Vertical
TR103: 100R; Potentiometer_Bourns_3314J_Vertical
TR104: 20k; Potentiometer_Bourns_3314J_Vertical
TR105: 1M; Potentiometer_Bourns_3314J_Vertical
U101: TL074; SOIC-14_3.9x8.7mm_P1.27mm
U102: LM13700; SOIC-16_3.9x9.9mm_P1.27mm
U103: TL072; SOIC-8_3.9x4.9mm_P1.27mm
U104: TL071; SOIC-8_3.9x4.9mm_P1.27mm
VR101, VR103, VR104, VR106: 100kB; RV16AF-41-(L)R1-XXX
VR102: 100kB; RD901F-40-00D
VR105: 100kA; RV16AF-41-(L)R1-XXX

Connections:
+10V: TR101.3, VR101.3 (1), VR102.3 (1); also elsewhere on the board
-10V: TR101.1, VR101.1 (3), VR102.1 (3); also elsewhere on the board
/Saw/+15V: C106.1, C108.1, C110.1, C112.1, Q102.3 (C1), Q103.2 (E), R118.1, R124.1, U101.4 (V+), U102.11 (V+), U103.8 (V+), U104.7 (V+), VR106.3 (1); also elsewhere on the board
/Saw/-15V: C107.2, C109.2, C111.2, C113.2, R110.2, R125.2, R130.2, R139.2, U101.11 (V-), U102.1, U102.6 (V-), U103.4 (V-), U104.4 (V-); also elsewhere on the board
GND: C106.2, C107.1, C108.2, C109.1, C110.2, C111.1, C112.2, C113.1, D102.2 (K), J104.1, J109.1, J110.1, J111.1, Q101.1 (B2), R106.1, R112.2, R114.2, R117.2, R119.2, R121.2, R122.1, R127.1, R128.2, R133.2, R136.2, R138.2, R141.2, R143.1, R144.1, R145.1, TR102.1, U101.5 (+), U102.3 (+), U102.4 (-), U102.7, U102.10, VR105.1 (3), VR106.1 (3); also elsewhere on the board
unnamed: C101.1, U101.6 (-), U102.12
unnamed: C101.2, D102.1 (K), Q102.2 (B1), R137.1, R140.1, R142.1, U101.7, U104.3 (+)
unnamed: C102.1, VR105.2
unnamed: C102.2, R109.1
unnamed: C103.1, Q101.6 (C2), R109.2, R110.1, U101.9 (-)
unnamed: C103.2, D101.3 (A), R115.1, U101.8
unnamed: C104.1, R145.2, R150.1, TR104.1, U103.6 (-)
unnamed: C104.2, R152.1, U103.7
unnamed: C105.1, R144.2, R149.1, U104.2 (-)
unnamed: C105.2, R151.1, U104.6
unnamed: D101.2 (K), TR102.3
unnamed: D102.3 (A), Q105.3 (G), R137.2, R138.1
unnamed: J101.1, R101.1
unnamed: J102.1, R102.1
unnamed: J103.1, R105.2
unnamed: J104.2, VR105.3 (1)
unnamed: J105.1, R128.1, R132.1
unnamed: J106.1, R134.2
unnamed: J106.2, R126.1, U103.2 (-)
unnamed: J106.3, R123.2
unnamed: J107.1, R127.2
unnamed: J107.2, TR105.3
unnamed: J107.3, R131.2
unnamed: J108.1, R147.1
unnamed: J108.2, Q105.2 (S), R141.1
unnamed: J108.3, R146.1
unnamed: J109.2, R149.2, R151.2
unnamed: J110.2, J111.2, R150.2, R152.2
unnamed: Q101.2 (B1), TR103.2
unnamed: Q101.3 (C1), U102.16
unnamed: Q101.4 (E1), Q101.5 (E2), R115.2
unnamed: Q102.1 (B2), R129.2, R130.1, R133.1, R134.1
unnamed: Q102.4 (E1), Q102.5 (E2), R123.1, R125.1
unnamed: Q102.6 (C2), Q103.1 (B), R124.2
unnamed: Q103.3 (C), R120.1, R129.1
unnamed: Q104.1 (D), R126.2, R131.1, U103.1
unnamed: Q104.2 (S), R148.1
unnamed: Q104.3 (G), TR105.2
unnamed: Q105.1 (D), R140.2
unnamed: R101.2, VR103.2
unnamed: R102.2, VR104.2
unnamed: R103.1, VR101.2
unnamed: R103.2, R104.2, R105.1, R107.1, R108.1, R113.2, R116.1, U101.13 (-), VR103.3 (1), VR104.3 (1)
unnamed: R104.1, VR102.2
unnamed: R106.2, U101.3 (+)
unnamed: R107.2, TR101.2
unnamed: R108.2, TR102.2
unnamed: R111.1, U101.2 (-), VR103.1 (3), VR104.1 (3)
unnamed: R111.2, R113.1, U101.1
unnamed: R112.1, U101.10 (+)
unnamed: R114.1, U101.12 (+)
unnamed: R116.2, TR103.3, U101.14
unnamed: R117.1, TR103.1
unnamed: R118.2, R119.1, U102.14 (+)
unnamed: R120.2, R121.1, U102.13 (-)
unnamed: R122.2, U103.3 (+)
unnamed: R132.2, R135.1, R136.1, R139.1, TR105.1
unnamed: R135.2, VR106.2
unnamed: R142.2, R143.2, TR104.2, TR104.3
unnamed: R146.2, R147.2, R148.2, U103.5 (+)

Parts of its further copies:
C201: 2n2; C_0805_2012Metric
C202: 22uF; CP_Elec_5x5.8
C203: 100p; C_0805_2012Metric
C204, C205: 220p; C_0805_2012Metric
C206, C207, C208, C209, C210, C211, C212, C213: 100n; C_0805_2012Metric
D201, D202: BAW56; SOT-23
J201: Vary CV 1; Johnson_108-09XX-001
J202: Vary CV 2; Johnson_108-09XX-001
J203: V/O; Johnson_108-09XX-001
J204: FM IN; Switchcraft_41
J205: Shape CV; Johnson_108-09XX-001
J206: SHAPE SEL 1; PinHeader_1x03_P2.54mm_Vertical
J207: SHAPE SEL 3; PinHeader_1x03_P2.54mm_Vertical
J208: SHAPE SEL 2; PinHeader_1x03_P2.54mm_Vertical
J209: Triangle Out; Switchcraft_41
J210: Final Out 1; Switchcraft_41
J211: Final Out 2; Switchcraft_41
Q201: DMMT3906W; SOT-363_SC-70-6
Q202: DMMT3904W; SOT-363_SC-70-6
Q203: MMBT3906; SOT-23
Q204: MMBF5485; SOT-23
Q205: MMBFJ201; SOT-23
R201, R202: 180k; R_0805_2012Metric
R203, R223, R228: 150k; R_0805_2012Metric
R204: 2M7; R_0805_2012Metric
R205: 120k; R_0805_2012Metric
R206, R209, R215, R222: 10k; R_0805_2012Metric
R207, R211, R213: 100k; R_0805_2012Metric
R208, R210: 1M5; R_0805_2012Metric
R212, R232: 390k; R_0805_2012Metric
R214, R245: 1k8; R_0805_2012Metric
R216: 2k; R_0805_2012Metric
R217: 390R; R_0805_2012Metric
R218, R244: 33k; R_0805_2012Metric
R219: 4k99; R_0805_2012Metric
R220, R226: 68k; R_0805_2012Metric
R221, R225, R230: 15k; R_0805_2012Metric
R224, R249: 3k3; R_0805_2012Metric
R227: 680k; R_0805_2012Metric
R229, R242, R243: 6k8; R_0805_2012Metric
R231, R236: 820k; R_0805_2012Metric
R233: 2k49; R_0805_2012Metric
R234, R237, R238, R239: 330k; R_0805_2012Metric
R235: 430k; R_0805_2012Metric
R240, R241, R248, R251, R252: 680R; R_0805_2012Metric
R246: 470R; R_0805_2012Metric
R247: 2k2; R_0805_2012Metric
R250: 9k1; R_0805_2012Metric
TR201, TR202: 100k; Potentiometer_Bourns_3314J_Vertical
TR203: 100R; Potentiometer_Bourns_3314J_Vertical
TR204: 20k; Potentiometer_Bourns_3314J_Vertical
TR205: 1M; Potentiometer_Bourns_3314J_Vertical
U201: TL074; SOIC-14_3.9x8.7mm_P1.27mm
U202: LM13700; SOIC-16_3.9x9.9mm_P1.27mm
U203: TL072; SOIC-8_3.9x4.9mm_P1.27mm
U204: TL071; SOIC-8_3.9x4.9mm_P1.27mm
VR201, VR203, VR204, VR206: 100kB; RV16AF-41-(L)R1-XXX
VR202: 100kB; RD901F-40-00D
VR205: 100kA; RV16AF-41-(L)R1-XXX

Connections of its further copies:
+10V: TR201.3, VR201.3 (1), VR202.3 (1); also elsewhere on the board
-10V: TR201.1, VR201.1 (3), VR202.1 (3); also elsewhere on the board
/Square/+15V: C206.1, C208.1, C210.1, C212.1, Q202.3 (C1), Q203.2 (E), R218.1, R224.1, U201.4 (V+), U202.11 (V+), U203.8 (V+), U204.7 (V+), VR206.3 (1); also elsewhere on the board
/Square/-15V: C207.2, C209.2, C211.2, C213.2, R210.2, R225.2, R230.2, R239.2, U201.11 (V-), U202.1, U202.6 (V-), U203.4 (V-), U204.4 (V-); also elsewhere on the board
GND: C206.2, C207.1, C208.2, C209.1, C210.2, C211.1, C212.2, C213.1, D202.2 (K), J204.1, J209.1, J210.1, J211.1, Q201.1 (B2), R206.1, R212.2, R214.2, R217.2, R219.2, R221.2, R222.1, R227.1, R228.2, R233.2, R236.2, R238.2, R241.2, R243.1, R244.1, R245.1, TR202.1, U201.5 (+), U202.3 (+), U202.4 (-), U202.7, U202.10, VR205.1 (3), VR206.1 (3); also elsewhere on the board
unnamed: C201.1, U201.6 (-), U202.12
unnamed: C201.2, D202.1 (K), Q202.2 (B1), R237.1, R240.1, R242.1, U201.7, U204.3 (+)
unnamed: C202.1, VR205.2
unnamed: C202.2, R209.1
unnamed: C203.1, Q201.6 (C2), R209.2, R210.1, U201.9 (-)
unnamed: C203.2, D201.3 (A), R215.1, U201.8
unnamed: C204.1, R245.2, R250.1, TR204.1, U203.6 (-)
unnamed: C204.2, R252.1, U203.7
unnamed: C205.1, R244.2, R249.1, U204.2 (-)
unnamed: C205.2, R251.1, U204.6
unnamed: D201.2 (K), TR202.3
unnamed: D202.3 (A), Q205.3 (G), R237.2, R238.1
unnamed: J201.1, R201.1
unnamed: J202.1, R202.1
unnamed: J203.1, R205.2
unnamed: J204.2, VR205.3 (1)
unnamed: J205.1, R228.1, R232.1
unnamed: J206.1, R234.2
unnamed: J206.2, R226.1, U203.2 (-)
unnamed: J206.3, R223.2
unnamed: J207.1, R227.2
unnamed: J207.2, TR205.3
unnamed: J207.3, R231.2
unnamed: J208.1, R247.1
unnamed: J208.2, Q205.2 (S), R241.1
unnamed: J208.3, R246.1
unnamed: J209.2, R249.2, R251.2
unnamed: J210.2, J211.2, R250.2, R252.2
unnamed: Q201.2 (B1), TR203.2
unnamed: Q201.3 (C1), U202.16
unnamed: Q201.4 (E1), Q201.5 (E2), R215.2
unnamed: Q202.1 (B2), R229.2, R230.1, R233.1, R234.1
unnamed: Q202.4 (E1), Q202.5 (E2), R223.1, R225.1
unnamed: Q202.6 (C2), Q203.1 (B), R224.2
unnamed: Q203.3 (C), R220.1, R229.1
unnamed: Q204.1 (D), R226.2, R231.1, U203.1
unnamed: Q204.2 (S), R248.1
unnamed: Q204.3 (G), TR205.2
unnamed: Q205.1 (D), R240.2
unnamed: R201.2, VR203.2
unnamed: R202.2, VR204.2
unnamed: R203.1, VR201.2
unnamed: R203.2, R204.2, R205.1, R207.1, R208.1, R213.2, R216.1, U201.13 (-), VR203.3 (1), VR204.3 (1)
unnamed: R204.1, VR202.2
unnamed: R206.2, U201.3 (+)
unnamed: R207.2, TR201.2
unnamed: R208.2, TR202.2
unnamed: R211.1, U201.2 (-), VR203.1 (3), VR204.1 (3)
unnamed: R211.2, R213.1, U201.1
unnamed: R212.1, U201.10 (+)
unnamed: R214.1, U201.12 (+)
unnamed: R216.2, TR203.3, U201.14
unnamed: R217.1, TR203.1
unnamed: R218.2, R219.1, U202.14 (+)
unnamed: R220.2, R221.1, U202.13 (-)
unnamed: R222.2, U203.3 (+)
unnamed: R232.2, R235.1, R236.1, R239.1, TR205.1
unnamed: R235.2, VR206.2
unnamed: R242.2, R243.2, TR204.2, TR204.3
unnamed: R246.2, R247.2, R248.2, U203.5 (+)

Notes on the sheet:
3300ppm PTC Mount with Q201
Coarse Frequency
Fine Tune
Sine Shape
Shape Zero
HF Trim
Frequency Offset
V/O Scale
Unused Gates
Power Filtering
CV Summing
Oscillator Core
Waveshaping
Output Amplifiers
Shape
1.2 V/O SOT for alt. V/O scales
~~4.5Vp-p
~~4.5Vp-p (Sine)
NOTES Select R105/R205 for V/O scale other than 1.2 V/O To match coarse frequency front panel scale R103/203 = 150k For reduced range R103/203 = 180k Select Q105/205 for VGS(off) of 0.8V - 1.2V. Ideal value is 1.13V for best sine shape Shape select headers: Connect pins 1 & 2 for square Connect pin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

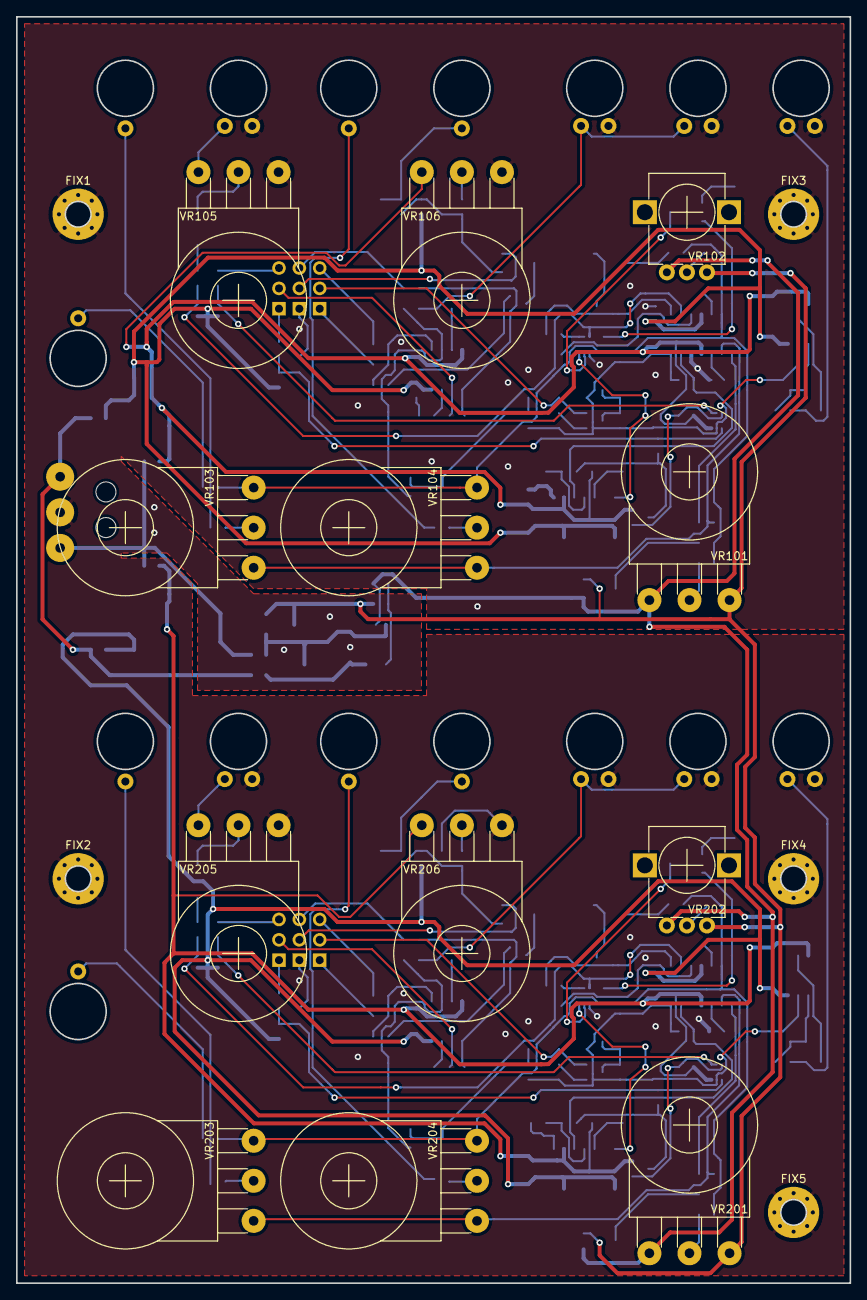
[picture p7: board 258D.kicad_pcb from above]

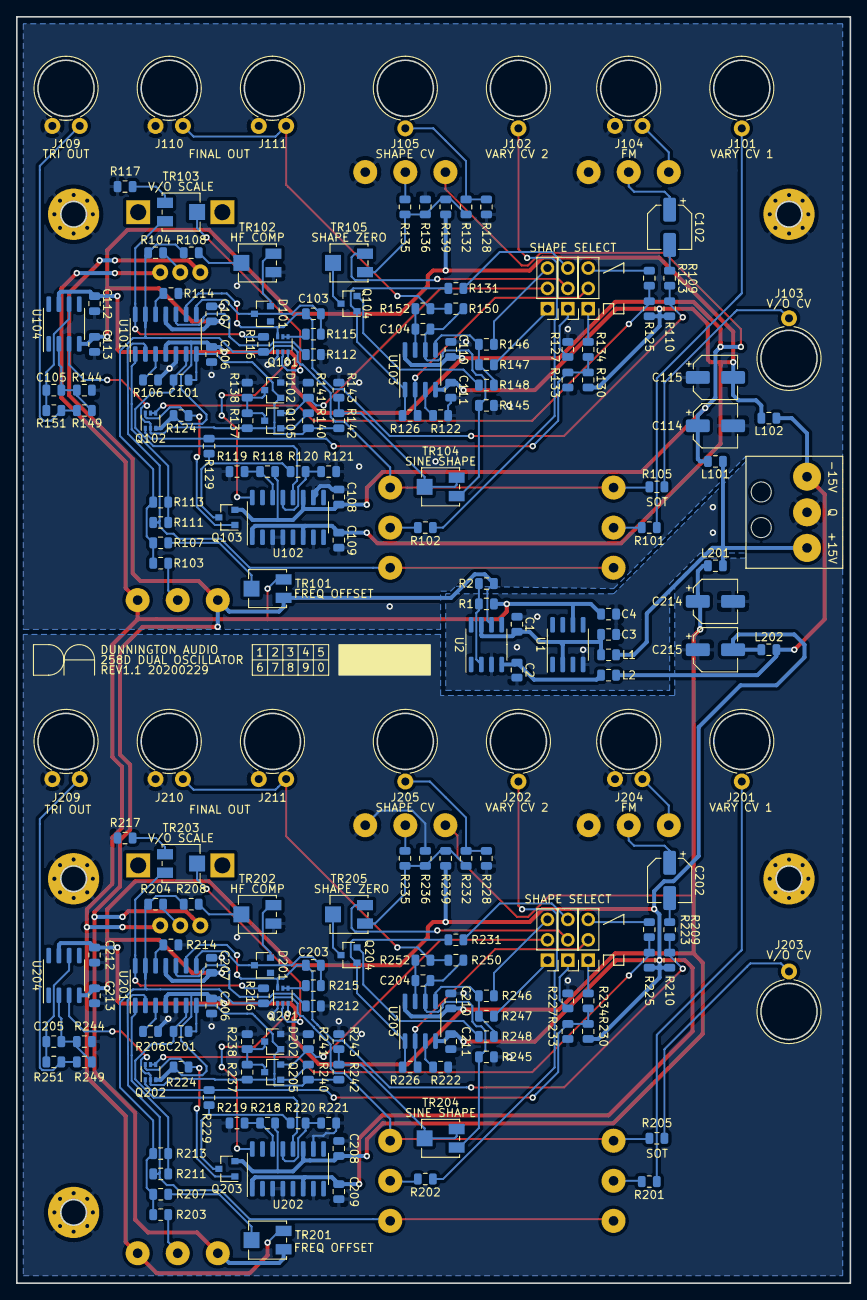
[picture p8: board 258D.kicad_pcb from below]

Board: 2 copper layers, 104.0 x 158.0 mm, 227 parts (210 on the bottom side), 132 nets.

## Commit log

2020-05-19 Update .gitignore, update BOM, add BOM pdf.
    [258D_Master_BOM.ods]
2020-06-10 Update BOM, BOM pdf, notes.
    [258D_Master_BOM.ods]
2020-06-29 Update BOM, BOM pdf, notes, schematic
    [258D.kicad_pcb, 258D.sch, 258D_Cell.sch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]
2020-08-21 Update BOM, BOM pdf
    [258D_Master_BOM.ods]
2020-11-13 Update Q104/204 value in schematic, board, BOM, iBOM, clarify selection criteria for Q105/205 in schematic, BOM, notes.
    [258D.kicad_pcb, 258D.sch, 258D_Cell.sch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]
